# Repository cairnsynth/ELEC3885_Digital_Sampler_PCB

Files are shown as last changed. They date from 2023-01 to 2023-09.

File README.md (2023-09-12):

# ELEC3885 Digital Sampler PCB

- Sample-based musical instrument aimed for use in education
- Capable of sequencing and playback of samples on 4 separate channels, and audio effects
- Developed using the Teensy 4.1 development board

## PCB Features

- USB/Li-Po battery power supply
- Audio I/O
	- Line level input/output
	- Headphone output with variable volume
	- Internal MEMS microphone
	- Balanced external microphone input
- User Interface
	- LCD
		- Sample information
		- File browser
		- Parameter values linked to encoders
	- Encoders
		- Control sample specific parameters
	- Potentiometers
		- Control global effects (reverb, filter)
	- RGB LEDs
		- Display sequence playback
	- Button Arrays
		- 8 button array for sample sequencing
		- 4 button array for instant sample playback

ELEC3885_Rev4_Render_Top

---

## Revisions

- Revisions are separated on different branches

### Rev1 (main branch)
- Initial prototype PCB layout containing
	- Teensy 4.1 mounting headers
	- SGTL5000 codec
	- Audio I/O
	- Breakout headers for internal microphone and differential amplifier testing
	- Basic UI

Prototype PCB 1 layout

### Rev2
- Layout alterations reducing length of traces for MCU-codec interfaces



### Rev3
- Switch to 4 layer board, 2 sided assembly
	- Analogue circuitry moved to back face
- External microphone differential amplifier added
- Power supply/Li-Po charging circuit added
- Integration of other group members work
	- LCD header and interface routing
	- LED and shift registers
	- Button arrays
	- Encoders/Pots
- Test points added for testing/debugging

### Rev4
- Changes to accommodate JLCPCB stock
	- Codec circuit redesign for QFN32 package of SGTL5000
	- SMD packages
- Trace teardrops added

PCB $

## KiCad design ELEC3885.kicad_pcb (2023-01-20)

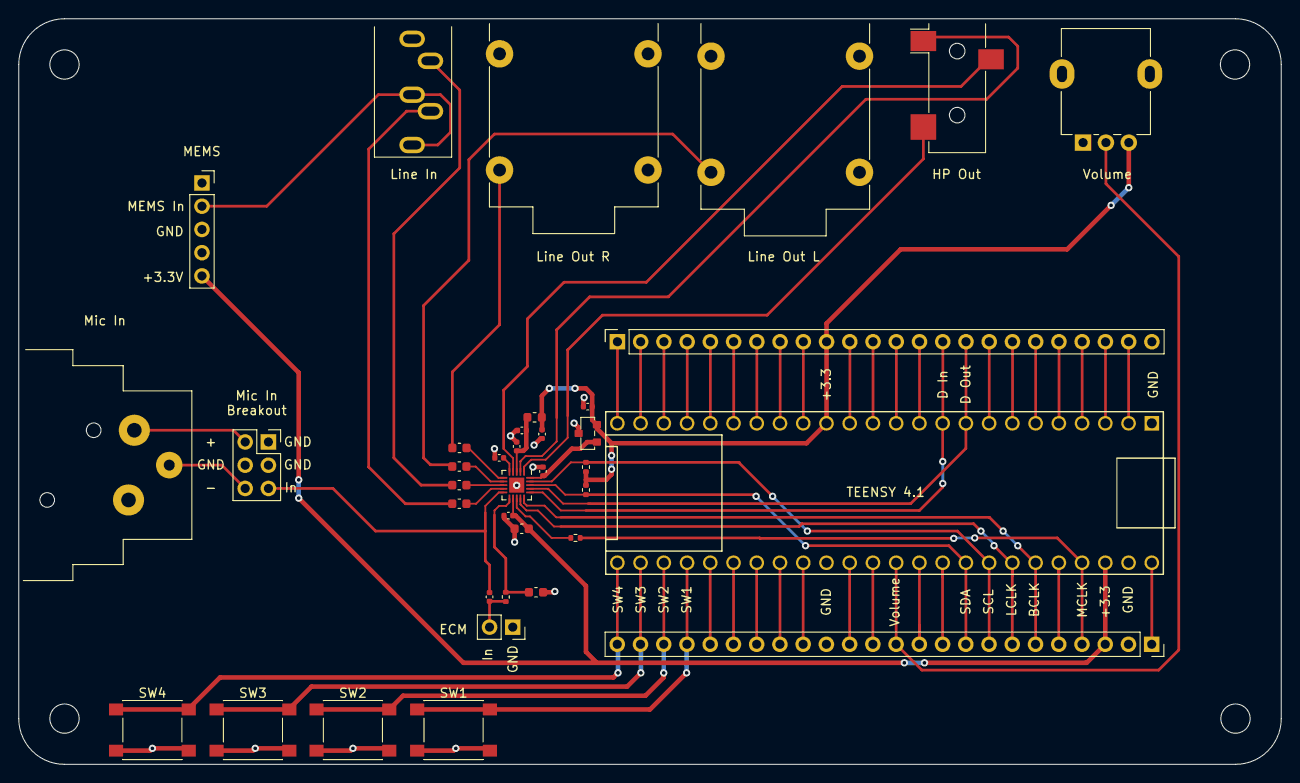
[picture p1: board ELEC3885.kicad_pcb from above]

Board: 2 copper layers, 138.0 x 81.5 mm, 41 parts (0 on the bottom side), 66 nets.

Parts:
C1: 10uF; C_0603_1608Metric
C2, C3, C6, C8, C14: 0.1uF; C_0402_1005Metric
C4, C5, C11, C12, C13: 2.2uF; C_0603_1608Metric
C7, C10: 1uF; C_0402_1005Metric
C9: 10nF; C_0402_1005Metric
FB1: FerriteBead; L_0603_1608Metric
H1, H2, H3, H4: MountingHole; MountingHole_3.2mm_M3
J1: MicInstIn; Jack_XLR_Neutrik_NC3FAAH-0_Horizontal
J2: LineIn; Jack_3.5mm_CUI_SJ1-3535NG_Horizontal
J3: HeadPhoneOut; Jack_3.5mm_CUI_SJ-3523-SMT_Horizontal
J4: LineOutR; Jack_6.35mm_Neutrik_NMJ4HCD2_Horizontal
J5: LineOutL; Jack_6.35mm_Neutrik_NMJ4HCD2_Horizontal
J6, J7: Conn_01x24_Female; PinSocket_1x24_P2.54mm_Vertical
J8: Conn_01x06_Female; PinSocket_2x03_P2.54mm_Vertical
J9: Conn_01x05_Female; PinSocket_1x05_P2.54mm_Vertical
MK1: InternalMic; PinSocket_1x02_P2.54mm_Vertical
R1: 1k; R_0402_1005Metric
R2, R3, R4: 2.2k; R_0402_1005Metric
RV1: 10k; Potentiometer_Alpha_RD901F-40-00D_Single_Vertical
SW1, SW2, SW3, SW4: SW_Push; SW_Push_1P1T_NO_6x6mm_H9.5mm
U1: AP7313; SOT23
U2: SGTL5000XNLA3; QFN-20-1EP_3x3mm_P0.4mm_EP1.65x1.65mm
U3: Teensy4.1; Teensy41

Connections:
+3.3V: C1.1, C2.1, C3.1, C7.1, FB1.1, J6.10, J7.3, J9.5, R2.2, R3.2, RV1.3, U1.1 (Vin), U2.12 (VDDIO), U3.15 (3V3), U3.46 (3V3)
/Audio/BCLK: J7.6, U2.15 (I2S_SCLK), U3.43 (21_A7_RX5_BCLK1)
/Audio/D_IN: J6.15, U2.16 (I2S_DOUT), U3.10 (8_TX2_IN1)
/Audio/D_OUT: J6.16, U2.17 (I2S_DIN), U3.9 (7_RX2_OUT1A)
/Audio/HP_L: J3.R, U2.4 (HP_L)
/Audio/HP_R: J3.T, U2.1 (HP_R)
/Audio/HP_VGND: J3.S, U2.2 (HP_VGND)
/Audio/LCLK: J7.7, U2.14 (I2S_LRCLK), U3.42 (20_A6_TX5_LRCLK1)
/Audio/LINE_IN_L: C5.1, J2.R
/Audio/LINE_IN_R: C4.1, J2.T
/Audio/LINE_OUT_L: C12.2, J5.T
/Audio/LINE_OUT_R: C11.2, J4.T
/Audio/MCLK: J7.4, R1.1, U3.45 (23_A9_CRX1_MCLK1)
/Audio/MEMS_IN: J2.RN, J2.TN, J9.2
/Audio/MIC_BIAS: C13.1, R4.1, U2.11 (MIC_BIAS)
/Audio/MIC_IN: C14.1, J8.6, U2.10 (MIC)
/Audio/SCL: J7.8, R2.1, U2.19 (CTRL_CLK), U3.41 (19_A5_SCL)
/Audio/SDA: J7.9, R3.1, U2.18 (CTRL_DATA), U3.40 (18_A4_SDA)
/Audio/VOLUME_CONTROL: J7.12, RV1.2, U3.37 (15_A1_RX3_SPDIF_IN)
/Teensy/BUTTON_0: J7.21, SW1.1, U3.28 (36_CS)
/Teensy/BUTTON_1: J7.22, SW2.1, U3.27 (35_TX8)
/Teensy/BUTTON_2: J7.23, SW3.1, U3.26 (34_RX8)
/Teensy/BUTTON_3: J7.24, SW4.1, U3.25 (33_MCLK2)
GND: C1.2, C2.2, C3.2, C6.1, C7.2, C8.2, C9.2, C10.2, C13.2, J1.1, J2.S, J4.S, J4.TN, J5.S, J5.TN, J6.24, J7.2, J7.15, J8.2, J8.4, J8.5, J9.3, MK1.1, RV1.1, SW1.2, SW2.2, SW3.2, SW4.2, U1.3 (GND), U2.21 (GND), U3.1 (GND), U3.34 (GND), U3.47 (GND)
unnamed: C4.2, U2.8 (LINEIN_R)
unnamed: C5.2, U2.9 (LINEIN_L)
unnamed: C6.2, U2.5 (VAG)
unnamed: C8.1, U1.2 (Vout), U2.20 (VDDD)
unnamed: C9.1, C10.1, FB1.2, U2.3 (VDDA)
unnamed: C11.1, U2.6 (LINEOUT_R)
unnamed: C12.1, U2.7 (LINEOUT_L)
unnamed: C14.2, MK1.2, R4.2
unnamed: J1.2, J8.1
unnamed: J1.3, J8.3
unnamed: J6.1, U3.24 (32_OUT1B)
unnamed: J6.2, U3.23 (31_CTX3)
unnamed: J6.3, U3.22 (30_CRX3)
unnamed: J6.4, U3.21 (29_TX7)
unnamed: J6.5, U3.20 (28_RX7)
unnamed: J6.6, U3.19 (27_A13_SCK1)
unnamed: J6.7, U3.18 (26_A12_MOSI1)
unnamed: J6.8, U3.17 (25_A11_RX6_SDA2)
unnamed: J6.9, U3.16 (24_A10_TX6_SCL2)
unnamed: J6.11, U3.14 (12_MISO_MQSL)
unnamed: J6.12, U3.13 (11_MOSI_CTX1)
unnamed: J6.13, U3.12 (10_CS_MQSR)
unnamed: J6.14, U3.11 (9_OUT1C)
unnamed: J6.17, U3.8 (6_OUT1D)
unnamed: J6.18, U3.7 (5_IN2)
unnamed: J6.19, U3.6 (4_BCLK2)
unnamed: J6.20, U3.5 (3_LRCLK2)
unnamed: J6.21, U3.4 (2_OUT2)
unnamed: J6.22, U3.3 (1_TX1_CTX2_MISO1)
unnamed: J6.23, U3.2 (0_RX1_CRX2_CS1)
unnamed: J7.1, U3.48 (VIN)
unnamed: J7.5, U3.44 (22_A8_CTX1)
unnamed: J7.10, U3.39 (17_A3_TX4_SDA1)
unnamed: J7.11, U3.38 (16_A2_RX4_SCL1)
unnamed: J7.13, U3.36 (14_A0_TX3_SPDIF_OUT)
unnamed: J7.14, U3.35 (13_SCK_LED)
unnamed: J7.16, U3.33 (41_A17)
unnamed: J7.17, U3.32 (40_A16)
unnamed: J7.18, U3.31 (39_MISO1_OUT1A)
unnamed: J7.19, U3.30 (38_CS1_IN1)
unnamed: J7.20, U3.29 (37_CS)
unnamed: R1.2, U2.13 (SYS_MCLK)

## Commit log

2023-01-16 PCB/ rm
    [ELEC3885.kicad_pcb, ELEC3885.kicad_sch]
2023-01-16 Audio board schematic added
    [ELEC3885.kicad_sch]
2023-01-16 Audio connections and internal mic added
    [ELEC3885.kicad_sch]
2023-01-16 Hierarchical sheets setup
    [ELEC3885.kicad_sch, ELEC3885_audio.kicad_sch, ELEC3885_power.kicad_sch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]
2023-01-19 Schematic work
    [ELEC3885.kicad_pcb, ELEC3885.kicad_sch, ELEC3885_audio.kicad_sch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]
2023-01-20 Initial schematic complete
    [ELEC3885.kicad_pcb, ELEC3885.kicad_sch, ELEC3885_audio.kicad_sch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]
